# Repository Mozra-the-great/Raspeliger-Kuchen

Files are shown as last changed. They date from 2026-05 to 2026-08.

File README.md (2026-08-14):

# Raspeliger-Kuchen

Unser Raspberry Pi Challenge Projekt — ein dezentrales IoT-System zur intelligenten Raumverwaltung mit Buchungssystem, KI-basierter Personenerkennung und automatischer Komfortsteuerung.

---

## Projektbeschreibung

Das System verwaltet vier Meetingräume (A–D) und verbindet Buchungslogik, Umgebungssensorik und Raumsteuerung in einer einheitlichen Plattform. Kernfunktionen:

- **Raumbuchung** über ein Web-Dashboard (Touchscreen-Kiosk + Browser)
- **KI-Personenerkennung** per Kamera und Hailo-8L AI Accelerator (YOLOv8s)
- **Automatische Komfortsteuerung** Licht, Rollos und Klimaanlage schalten sich beim Betreten automatisch ein
- **No-Show Auto-Release** nicht angetretene Buchungen werden nach Timeout freigegeben
- **Live-Sensordaten** Temperatur, Luftfeuchte und CO₂ pro Raum mit Handlungsempfehlungen
- **Home Assistant Automationen** für die Komfortlogik

---

## Hardware

| Node | IP | Rolle | Hardware-Besonderheit |
|---|---|---|---|
| Pi 1 — Webserver | 192.168.1.211 | Flask-Webserver, REST-API, Hailo-8L KI (Personenerkennung) | Hailo-8L M.2 HAT+ (Firmware 4.23.0, identifiziert als "Hailo-8") |
| Pi 2 — Datenbank | 192.168.1.206 | MariaDB 11.8.6, Mosquitto MQTT-Broker, Raumfreigabe-Logik | — |
| Pi 3 — Sensorik | 192.168.1.233 | DHT22, SCD30 (CO₂), Kamera-Modul, UDP-Stream | I²C (`dtparam=i2c_arm=on`), CSI-Kamera (`camera_auto_detect=1`) |
| Pi 4 — Automatisierung | 192.168.1.210 | Home Assistant OS (Port 8123) | kein SSH (Web-UI + File-Editor-Add-on) |
| Pi 5 — GUI | 192.168.1.232 | Touchscreen-Kiosk (Chromium, labwc/Wayland) | Touchscreen (kapazitiv, HDMI-A-2) |

Netzwerk: alle Pis statisch über NetworkManager (`Wired connection 1`), Gateway 192.168.1.3, DNS 1.1.1.1 + 8.8.8.8.

---

## Tech-Stack

- **Backend:** Python / Flask 3.0.0, MariaDB 11.8.6, `paho-mqtt`, `pymysql`
- **Frontend:** Vanilla JS, HTML/CSS (Dark Theme, Kiosk-optimiert mit `clamp()`/`vw`/`vh`)
- **IoT:** MQTT (Mosquitto), Home Assistant OS
- **KI:** YOLOv8s (`yolov8s_h8l.hef`) auf Hailo-8L Accelerator (`hailort==4.23.0`)
- **Kamera:** `rpicam-vid` (1080p@30fps UDP) → `ffmpeg` (5 fps JPEG)
- **Sensoren:** DHT22 (Temp/Feuchte via `pigpio`), SCD30 (Temp/Feuchte/CO₂ via I²C/`adafruit-circuitpython-scd30`)
- **Wetter:** Open-Meteo API (Stuttgart)
- **OS:** Raspberry Pi OS Bookworm/Trixie 64-bit (Pi 1/2/3/5), Home Assistant OS (Pi 4), Pi 5 mit Wayland-Compositor `labwc`

---

## Repository-Struktur

```
.
├── app.py, person_detection.py, debug_server.py    Pi 1: Flask + KI
├── sensor_mqtt.py, DHT22.py, test_*.py             Pi 3: Sensor-Skripte
├── config.example.py                               Pi 1: Config-Template
├── *.service                                       systemd Units (Pi 1 + Pi 3)
├── configuration.yaml, automations.yaml,           Pi 4: Home Assistant
│   scripts.yaml, scenes.yaml, secrets.example.yaml
├── ha_automations_prod_v1.yaml,                    Pi 4: Komfort-Automationen
│   ha_automations_test_v2.yaml
├── schema.sql, raeume_seed.sql                     Pi 2: MariaDB
├── requirements_pi1.txt, requirements_pi3.txt      Pip-Pakete
├── install_emoji.sh                                Pi 5: Setup-Skript
├── README.md, ARCHITECTURE.md                      Doku
│
├── static/                                         Pi 1: Flask-Assets
│   ├── style.css, detail.css
│   └── dashboard.js, detail.js
├── templates/                                      Pi 1: Flask-Templates
│   ├── index.html
│   └── raum_detail.html
├── pi2/mosquitto/                                  Pi 2: MQTT-Config
│   ├── mosquitto.conf
│   └── conf.d/default.conf
├── pi3/                                            Pi 3: Boot-Config
│   └── boot_config.txt
└── pi5/                                            Pi 5: Kiosk-Setup
    ├── labwc-autostart
    ├── labwc-environment
    └── labwc-rc.xml
```

---

## Architektur

Eine vollständige Beschreibung aller Komponenten, Datenflüsse, MQTT-Topics und Setup-Schritte findet sich in [ARCHITECTURE.md](ARCHITECTURE.md).

---

## Lizenz

GNU General Public License v3.0 — siehe [LICENSE](LICENSE).

Das Projekt stand ursprünglich unter der MIT-Lizenz. Die Umstellung auf GPLv3
erfolgte 2026 mit Zustimmung aller Copyright-Inhaber (Moritz, Nick, Niklas, Robin).

`DHT22.py` enthält Code aus den pigpio-Beispielen (Joan2937, Public Domain).

---

*Robin, Nick, Niklas, Moritz — 2026*

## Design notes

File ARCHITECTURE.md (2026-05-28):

# Architektur: Raspeliger-Kuchen

Dezentrales IoT-System zur intelligenten Raumverwaltung mit Buchungen, KI-basierter Personenerkennung und automatischer Komfortsteuerung. Das System verteilt sich auf mehrere Raspberry Pi Nodes, die über MQTT kommunizieren, mit Home Assistant als zentraler Automationsschicht und Flask als Backend.

---

## Systemübersicht

```
┌──────────────────────────────────────────┐
│  Pi 3 — Sensorik (192.168.1.233)         │
│  kamera-stream.service:                  │
│    rpicam-vid 1080p@30fps                │
│    → UDP 192.168.1.211:9000              │
│  sensor.service:                         │
│    sensor_mqtt.py (DHT22 + SCD30)        │
│    → MQTT sensor/raum_a/*               │
└────────┬─────────────────────────────────┘
         │ UDP :9000          │ MQTT sensor/*
┌────────▼──────────────────────────────────────┐
│  Pi 1 — Webserver (192.168.1.211)              │
│                                                │
│  ffmpeg-stream.service:                        │
│    ffmpeg udp://@:9000 → /tmp/frame.jpg @5fps  │
│  person-detection.service:                     │
│    Hailo-8 YOLOv8s → MQTT room/raum_a/occupied │
│  debug-server.service → debug_server.py :5001  │
│  dashboard.service    → app.py :5000           │
└────────┬───────────────────────────────────────┘
         │ MQTT + MariaDB-Verbindung
┌────────▼──────────────────────────────────┐
│  Pi 2 — Datenbank (192.168.1.206)         │
│  MQTT Broker (Mosquitto) :1883            │
│  MariaDB :3306 (DB: raumverwaltung)       │
└────────┬──────────────────────────────────┘
         │ MQTT (cmd/*, room/*, state/*)
┌────────▼──────────────────────────────────┐
│  Pi 4 — Automatisierung (192.168.1.210)   │
│  Home Assistant :8123                     │
│  configuration.yaml, automations.yaml     │
│  ha_automations_prod_v1.yaml              │
└────────┬──────────────────────────────────┘
         │ HTTP
┌────────▼──────────────────────────┐
│  Pi 5 — GUI (192.168.1.232)       │
│  Touchscreen-Kiosk                │
│  Chromium → http://192.168.1.211  │
└───────────────────────────────────┘
```

---

## Netzwerk & IP-Adressen

| Node | IP | Rolle |
|---|---|---|
| Pi 1 — Webserver | 192.168.1.211 | Flask :5000, Hailo-8L KI, FFmpeg-Empfänger, Debug-Server :5001 |
| Pi 2 — Datenbank | 192.168.1.206 | MariaDB :3306, MQTT Broker :1883 |
| Pi 3 — Sensorik | 192.168.1.233 | DHT22, SCD30, Kamera-Streamer (UDP) |
| Pi 4 — Automatisierung | 192.168.1.210 | Home Assistant :8123 |
| Pi 5 — GUI | 192.168.1.232 | Touchscreen-Kiosk (Chromium, labwc) |

**Statische IPs via NetworkManager** (verifiziert 2026-05-28). Alle Pis nutzen Profil `Wired connection 1` auf `eth0`:
- `ipv4.method = manual`
- Gateway: `192.168.1.3`
- DNS: `1.1.1.1, 8.8.8.8` (Pi 5 hat nur `1.1.1.1`)

Beispiel-Konfiguration für einen neuen Pi:
```bash
sudo nmcli con modify "Wired connection 1" \
  ipv4.method manual \
  ipv4.addresses 192.168.1.XXX/24 \
  ipv4.gateway 192.168.1.3 \
  ipv4.dns "1.1.1.1,8.8.8.8"
sudo nmcli con up "Wired connection 1"
```

> Hinweis: Auf neueren Raspberry-Pi-OS-Versionen (Bookworm/Trixie) wird NetworkManager statt `dhcpcd` verwendet. `/etc/dhcpcd.conf` existiert dort nicht mehr.

---

## MQTT Topic-Schema

```
# Anwesenheit (Kamera-KI → app.py/HA)
room/raum_a/occupied          → "true" | "false"  (retain=true bei Release)

# Sensordaten (Sensor-Pi → app.py)
sensor/raum_a/temperatur      → float (°C)
sensor/raum_a/luftfeuchte     → float (%)
sensor/raum_a/co2             → int (ppm)
sensor/raum_a/dht22/temperatur → float (Rohwert DHT22)
sensor/raum_a/scd30/temperatur → float (Rohwert SCD30)

# Steuerbefehle (app.py → Hardware via HA)
cmd/raum_a/licht              ← "on" | "off"
cmd/raum_a/rollo              ← "up" | "down" | "stop"
cmd/raum_a/klima_modus        ← "off" | "heat" | "cool"
cmd/raum_a/klima_soll         ← "15"-"30" (int als String)

# Hardware-State-Feedback (Hardware → app.py)
state/raum_a/licht            → aktueller Zustand
state/raum_a/rollo            → aktueller Zustand
```

---

## Flask REST API (Pi 1 :5000)

Verifiziert aus `app.py`. Flask-Verzeichnis auf Pi 1: `/home/raspi/dashboard_mariadb/`

```
GET  /
     → render_template("index.html")

GET  /raum/<raum_id>
     → render_template("raum_detail.html", raum_id, raum_name)

GET  /api/raeume
     → [{name, belegt, nutzer, bis, naechste_buchung, anwesenheit}]
     # Sonderfall: MQTT occupied=true ohne Buchung → nutzer="Anwesend"

POST /buchen
     ← {raum, nutzer, start, ende}
     → {status: "ok"|"error", id|nachricht}

POST /buchen-schnell
     ← {raum, dauer_minuten, nutzer}
     → {status, id, start, ende}

GET  /api/raum/<raum_name>/buchungen?datum=YYYY-MM-DD
     → [{id, nutzer, start, ende, start_voll, ende_voll, status}]
     # status: "aktiv" | "geplant" | "vorbei"

GET  /api/raum/<raum_id>/anwesenheit
     → {occupied: bool|null, last_update: "YYYY-MM-DD HH:MM:SS"|null, alter_sek: int|null}

GET  /api/raum/<raum_name>/status
     → {licht, rollo, klima_modus, klima_soll, checkin, letzte_aenderung}

POST /api/raum/<raum_name>/licht
     ← {action: "on"|"off"|"toggle"}
     → {status: "ok", state: {...}}

POST /api/raum/<raum_name>/rollo
     ← {action: "up"|"stop"|"down"}
     → {status: "ok", state: {...}}

POST /api/raum/<raum_name>/klima
     ← {modus: "heat"|"cool"|"off"}  ODER  {soll: int (15-30)}
     → {status: "ok", state: {...}}

POST /api/raum/<raum_name>/checkin
     → {status: "ok", state: {...}}
     # Achtung: toggled nur In-Memory-Flag, schreibt NICHT checked_in_at in DB

GET  /api/sensoren
     → {temperatur, luftfeuchte, co2, zeitstempel, quelle, raum}
     # Liest HAUPT_RAUM aus config.py

GET  /api/sensoren/<raum_id>
     → {temperatur, luftfeuchte, co2, zeitstempel, raum}

GET  /api/raum/<raum_name>/verlauf
     → [{zeit, temperatur, luftfeuchte, co2}]  (24h, Demo-Daten)

GET  /api/wetter
     → {ort, current, forecast, tag, abgerufen}

GET  /api/verkehr
     → {status: "gruen"|"gelb"|"rot", label, beschreibung, details}

GET  /api/status
     → {zeit, db: "ok"|"error: ...", mqtt: {aktiv, raeume_mit_daten}}

POST /stornieren/<buchung_id>
     → {status: "ok"|"error", nachricht}

POST /raum/<raum_name>/frei
     → {status: "ok", id}  (HA No-Show-Trigger)
     # Setzt storniert=TRUE + publisht room/raum_x/occupied="false" (retain)
```

---

## Dateien

### `app.py` — Flask-Backend (Pi 1)

Zentrale Backend-Anwendung. Version 3. Liegt auf Pi 1 unter `/home/raspi/dashboard_mariadb/app.py`.

**Importiert aus `config.py`:**
```python
DB_CONFIG      # pymysql Verbindungsparameter
FLASK_HOST     # z.B. "0.0.0.0"
FLASK_PORT     # z.B. 5000
DEBUG          # bool
MQTT_CONFIG    # {host, port, username, password, keepalive}
MQTT_TOPICS    # Liste von Topics zum Subscriben
HAUPT_RAUM     # z.B. "raum_a" — Standard-Raum für /api/sensoren
MOCK_SENSORS   # bool — liefert Zufallswerte statt MQTT-Daten
MQTT_ENABLED   # bool
SCHWELLWERTE   # dict (wird importiert, aber in app.py nicht direkt verwendet)
```

**In-Memory-Caches (Thread-sicher via Locks):**

| Cache | Typ | Inhalt |
|---|---|---|
| `sensor_cache` | `{raum: {typ: (wert, datetime)}}` | Letzte MQTT-Sensorwerte |
| `belegung_cache` | `{raum: bool}` | Letzter `occupied`-Status |
| `belegung_timestamps` | `{raum: datetime}` | Zeitstempel des letzten MQTT-Updates |
| `control_state` | `{raum: {licht, rollo, klima_modus, klima_soll, checkin}}` | Gerätezustände (In-Memory, kein DB-Persist) |
| `wetter_cache` | `{data, ts}` | Wetter-Response, 10-Min TTL |
| `verkehr_cache` | `{status, last_change, next_change}` | Demo-Verkehrsstatus |

**MQTT `on_message` Routing:**
```
topic prefix "sensor/" → sensor_cache aktualisieren
topic prefix "room/"   → belegung_cache + belegung_timestamps aktualisieren
                         + mark_checked_in() aufrufen (Auto-Check-in)
topic prefix "state/"  → control_state aktualisieren
```

**`mark_checked_in(raum_anzeige)`:**
Wird bei MQTT `occupied=true` automatisch aufgerufen. Schreibt `checked_in_at = NOW()` in die DB auf die aktive Buchung — verhindert Auto-Release.

**`auto_release_loop()` — Background-Thread:**
- Läuft als Daemon-Thread, prüft alle 30 Sekunden
- SQL: `storniert=0 AND abgelaufen=0 AND checked_in_at IS NULL AND start <= NOW() - INTERVAL 1 MINUTE AND ende >= NOW()`
- Setzt `abgelaufen=1` (nicht `storniert`) — logisch unterschiedlich vom manuellen Storno
- **Achtung Bug:** Kommentar sagt "10 Min", SQL-Query löst aber bereits nach **1 Minute** aus

**Doppelter Auto-Release-Mechanismus:**
1. `auto_release_loop()` im Backend (alle 30s, SQL-basiert, setzt `abgelaufen=1`)
2. HA-Automation `ha_automations_prod_v1.yaml` (10-Min Timeout, setzt `storniert=TRUE` via `/raum/x/frei`)
Beide können unabhängig feuern — keine Deduplizierung.

**`fetch_verkehr()` — reines Demo:**
Simuliert Verkehr mit zufälligen Gewichtungen nach Tageszeit. Keine echte Verkehrs-API.

**Raum-ID Konvention:**
- URL-Parameter `raum_name` = `"raum_a"` (Kleinbuchstaben, Unterstrich)
- Intern: `raum_name.replace("_", " ").title()` → `"Raum A"` (für DB + control_state Key)
- `belegung_cache` Key: `raum["name"].lower().replace(" ", "_")` → `"raum_a"`

**Bekannter Bug — manueller Check-In:**
`POST /api/raum/<raum>/checkin` toggled nur `control_state["checkin"]` im RAM.
`checked_in_at` in der DB wird **nicht** gesetzt.
Folge: Manueller Check-In über den Button verhindert den Auto-Release **nicht**.
Auto-Release läuft trotzdem. Nur MQTT-Anwesenheitserkennung schreibt in die DB.

---

### `config.py` — Konfiguration (Pi 1, gitignored)

Liegt unter `/home/raspi/dashboard_mariadb/config.py`. Enthält alle Secrets und Einstellungen die `app.py` importiert. Ist via `.gitignore` ausgeschlossen — `config.example.py` dient als sanitisiertes Template.

Tatsächliche Struktur:
```python
DB_CONFIG = {
    "host": "localhost",
    "port": 3306,
    "user": "...",
    "password": "...",
    "database": "..."
}
FLASK_HOST = "0.0.0.0"
FLASK_PORT = 5000
DEBUG = False
MQTT_CONFIG = {
    "host": "192.168.1.206",
    "port": 1883,
    "username": "raspi",
    "password": "raspi",
    "keepalive": 60
}
MQTT_TOPICS = ["sensor/#", "room/#", "state/#"]
HAUPT_RAUM = "raum_a"
MOCK_SENSORS = False
MQTT_ENABLED = True
SCHWELLWERTE = { ... }
```

---

### `configuration.yaml` — Home Assistant Hauptkonfiguration

Definiert alle MQTT-basierten Entities und REST-Sensoren.

**MQTT Lights** (`light.licht_raum_a/b/c/d`)
- Command-Topic: `cmd/raum_x/licht`
- Payloads: `on` / `off`
- `optimistic: true` — HA schaltet UI sofort, unabhängig vom Hardware-Feedback
- QoS: 1

**MQTT Covers** (`cover.rollo_raum_a/b/c/d`)
- Topics: `cmd/raum_x/rollo`
- Payload open/close/stop: `up` / `down` / `stop`
- QoS: 1

**MQTT Climate** (`climate.klima_raum_a/b/c/d`)
- Modi: `off`, `heat`, `cool`
- Mode-Command-Topic: `cmd/raum_x/klima_modus`
- Temperatur-Soll-Topic: `cmd/raum_x/klima_soll`
- Temperatur-Ist-Topic: `sensor/raum_x/temperatur`
- Bereich: 15–30°C, Schrittweite 1°C

**MQTT Sensors** (nur Raum A vollständig aktiviert)
- `sensor.temperatur_raum_a` ← `sensor/raum_a/temperatur`
- `sensor.luftfeuchte_raum_a` ← `sensor/raum_a/luftfeuchte`
- `sensor.co2_raum_a` ← `sensor/raum_a/co2`

**MQTT Binary Sensors** (`binary_sensor.anwesenheit_raum_a/b/c/d`)
- Topic: `room/raum_x/occupied`, Payloads: `"true"` / `"false"`
- Device-Class: `occupancy`

**MQTT Switches** (`switch.raum_a/b/c/d_belegt`)
- Topic: `room/raum_x/occupied`, Retain: true

**REST-Sensoren** (`sensor.buchung_aktiv_a/b/c/d`)
- Endpoint: `GET http://192.168.1.211:5000/api/raeume`, Poll: 30s
- Jinja2-Logik: `on` wenn `belegt == true` UND `nutzer != "Anwesend"`
- `"Anwesend"` ist der Sonder-Nutzername den `app.py` setzt wenn MQTT occupied=true aber keine Buchung aktiv ist — damit triggern reine Kamera-Erkennungen keine HA-Buchungsautomation

**REST-Command** (`rest_command.raum_frei`)
- `POST http://192.168.1.211:5000/raum/{raum_id}/frei`

---

### `automations.yaml` — HA Basisautomation

Einfache No-Show Auto-Release (Basisversion, ohne Komfortsteuerung).

Trigger: `sensor.buchung_aktiv_a/b/c/d` → `"on"`
Ablauf: Wartet 10 Min auf Anwesenheit → bei Timeout: `rest_command.raum_frei` + Notification
Mode: `parallel`, max. 4

---

### `ha_automations_prod_v1.yaml` — Produktionsautomationen

Vollständige Komfort- + No-Show-Automationen für alle 4 Räume.

Pro Raum jeweils 3 Blöcke:

**"Buchung Komfort"** (Trigger: `buchung_aktiv_x` → `"on"`)
- Licht AN, Rollo AUF, Klima ein (Mai–Sept: Kühlen 22°C, sonst: Heizen 21°C)
- Wartet 10 Min auf Anwesenheit — bei Timeout: Alles aus
- Mode: `restart`

**"Person erkannt"** (Trigger: `anwesenheit_raum_x` → `"on"`)
- Identische Komfort-Aktionen
- Mode: `single`, `max_exceeded: silent`

**"Person weg"** (Trigger: `anwesenheit_raum_x` → `"off"`)
- Bedingung: keine aktive Buchung
- Delay 2 Min → erneute Prüfung → Alles aus
- Mode: `restart`

**"No-Show Auto-Release"** (zentral, alle 4 Räume)
- Raum-ID aus `trigger.entity_id` extrahiert
- 10 Min Timeout → `rest_command.raum_frei` + Notification
- Mode: `parallel`, max. 4

---

### `ha_automations_test_v2.yaml` — Testautomationen

Identisch zu Prod, aber mit drastisch kürzeren Timeouts.

| | Prod | Test |
|---|---|---|
| Buchung Komfort Timeout | 10 Min | 10 Sek |
| Person weg Delay | 2 Min | 30 Sek |
| No-Show Release | 10 Min | 30 Sek |

Zusätzlich: "Buchung Ende" (Trigger: `buchung_aktiv_x` → `"off"`, Alles aus wenn niemand da)

---

### `index.html` — Haupt-Dashboard

Flask-Template (`render_template("index.html")`). Kiosk-Ansicht auf Pi 5.

Linke Spalte: Wetter Stuttgart, 3-Tage-Forecast, Sonnenauf/-untergang + UV, Verkehr
Rechte Spalte: 4 Raumkarten (Frei/Belegt, Nutzer, bis, nächste Buchung), Buchungsmodal

Im Repo unter `templates/index.html`. Auf Pi 1 deployed nach `/home/raspi/dashboard_mariadb/templates/index.html`.

---

### `raum_detail.html` — Raum-Detailseite

Flask-Template, aufgerufen von `GET /raum/<raum_id>`.
`raum_id` und `raum_name` werden als `data-*`-Attribute auf `<body>` gesetzt.

Sektionen: Header + Status-Badge, Sensoren-Zeile (3 Mini-Cards), Komfort-Card (Datum/KW + Anwesenheit), Buchungs-Timeline (3 Tabs), Steuerung (Licht/Rollo/Klima), Schnell-Aktionen, Toast

Im Repo unter `templates/raum_detail.html`. Auf Pi 1 deployed nach `/home/raspi/dashboard_mariadb/templates/raum_detail.html`.

---

### `style.css` — Styling Haupt-Dashboard

Dark Theme (`#0f172a` / `#1e293b`). Adaptives Layout für Touchscreen 800×480 und Laptop-Browser, vollständig responsive via `clamp()`, `vw`, `vh` — keine Media-Queries für Bildschirmbreite.

Akzent: `#38bdf8` (cyan). Status-Farben: Frei/Belegt-Badges (`#16a34a`/`#ef4444`), Verkehr-Ampel (grün/gelb/rot).

Buttons mind. 50 px hoch, touch-freundlich. Modal mit `backdrop-filter: blur(4px)`.

Im Repo unter `static/style.css`. Auf Pi 1 deployed nach `/home/raspi/dashboard_mariadb/static/style.css`.

---

### `detail.css` — Styling Raum-Detail

Dark Theme (`#0f172a` / `#1e293b`). Responsive via `clamp()` und Media-Query <520px Höhe.

Farben: OK `#22c55e`, Warn `#fbbf24`, Kritisch `#ef4444`, Unbekannt `#64748b`, Akzent `#38bdf8`

Im Repo unter `static/detail.css`. Auf Pi 1 deployed nach `/home/raspi/dashboard_mariadb/static/detail.css`.

---

### `dashboard.js` — Frontend-Logik Dashboard

Version `dropdowns-v2-20260527`. Polling-Intervalle:

| Funktion | Intervall | Endpoint |
|---|---|---|
| `updateClock()` | 1s | — |
| `ladeRaeume()` | 30s | `GET /api/raeume` |
| `ladeVerkehr()` | 60s | `GET /api/verkehr` |
| `ladeWetter()` | 600s | `GET /api/wetter` |

Buchungsmodal: `fuelleDatumOptionen()` (15 Tage), `fuelleZeitOptionen()` (8:00–18:00, 30-Min), `naechsteHalbeStunde()` (Vorauswahl). Speichern via `POST /buchen`.

Im Repo unter `static/dashboard.js`. Auf Pi 1 deployed nach `/home/raspi/dashboard_mariadb/static/dashboard.js`.

---

### `detail.js` — Frontend-Logik Raum-Detail

Version `compact-3sections-v10-20260527`. Polling-Intervalle:

| Funktion | Intervall | Endpoint |
|---|---|---|
| `loadPresence()` | 5s | `GET /api/raum/{id}/anwesenheit` |
| `loadControlState()` | 5s | `GET /api/raum/{id}/status` |
| `loadSensors()` | 10s | `GET /api/sensoren/{id}` |
| `loadBookings()` | 30s | `GET /api/raum/{id}/buchungen?datum=...` |

Sensor-Schwellwerte:

| Sensor | OK | Warn | Kritisch |
|---|---|---|---|
| Temperatur | 19–24°C | 17–26°C | außerhalb |
| Luftfeuchte | 40–60% | 30–70% | außerhalb |
| CO2 | 0–1000 ppm | 0–1400 ppm | >1400 ppm |

Timeline: Zeitbereich 07:00–20:00, Lane-System für Überlappungen, Jetzt-Linie (nur heute).
Anwesenheit: `true` → 👤 blau, `false` → 🚪 grau, `null` → ⏳ grau.

Im Repo unter `static/detail.js`. Auf Pi 1 deployed nach `/home/raspi/dashboard_mariadb/static/detail.js`.

---

### `person_detection.py` — KI-Personenerkennung (Pi 1)

YOLOv8s auf Hailo-8 AI Accelerator. Liest `/tmp/frame.jpg` (von Pi 3), führt Inferenz durch, publisht `room/raum_a/occupied`.

Glättung: Sliding Window über 5 Frames — `true` nur wenn ≥3 von 5 positiv.
Fallback: `last_good_frame` wenn Frame nicht lesbar.

```python
MQTT_HOST = "192.168.1.206"
CONFIDENCE = 0.3
SEND_INTERVAL = 5
HEF_PATH = "/usr/share/hailo-models/yolov8s_h8l.hef"
```

---

### `sensor_mqtt.py` — Sensor-Publisher (Pi 3)

DHT22 (GPIO 4) + SCD30 (I2C). Publiziert sekündlich an `sensor/raum_a/*`.
Primary: SCD30, Fallback: DHT22. Je 10 Leseversuche mit Delay.

---

### `debug_server.py` — Kamera-Debug (Pi 1, :5001)

MJPEG-Stream mit eingezeichneten Bounding Boxes. Liest `/tmp/frame.jpg` + `/tmp/detections.json`.
Rotiert Frame 180° (Kamera hängt umgekehrt). Qualität 70, 500ms Delay.

---

### `stream_test.py` — Einmaliger Verbindungstest

Liest einen Frame von `udp://@:9000` und speichert nach `/home/raspi/test_stream.jpg`. Zur Verifikation des UDP-Streams von Pi 3.

---

### `patch_anwesenheit.py` — Einmaliger Patch (veraltet)

Fügte `belegung_timestamps` und `/api/raum/<id>/anwesenheit` zu einer älteren Version von `app.py` hinzu. Beide Features sind in der aktuellen `app.py` bereits integriert — dieses Skript ist obsolet.

---

### `patch_buchungen.py` — Einmaliger Patch (veraltet)

Ersetzte den alten Buchungs-Endpoint durch die datumsgefilterte Version mit Status-Berechnung. Ebenfalls in der aktuellen `app.py` integriert — obsolet.

---

### `raeume_seed.sql` — Initialdaten Räume (Pi 2)

INSERT-Statements für die `raeume`-Tabelle, weil `schema.sql` nur die Tabellendefinition enthält (mit `kapazitaet DEFAULT 4`). Reale Kapazitäten weichen ab:
- Raum A: 6 Plätze
- Raum B: 4 Plätze
- Raum C: 8 Plätze
- Raum D: 4 Plätze

Einspielen nach `schema.sql`:
```bash
sudo mysql raumverwaltung < raeume_seed.sql
```

---

### `pi2/mosquitto/mosquitto.conf` + `conf.d/default.conf` — MQTT-Broker (Pi 2)

Spiegelung von `/etc/mosquitto/` auf Pi 2. Hauptkonfig lädt `conf.d/`. Listener auf 1883, `allow_anonymous false`, Auth über `/etc/mosquitto/passwd` (eine Zeile: `raspi:<hash>`).

Persistence in `/var/lib/mosquitto/`, Logfile in `/var/log/mosquitto/mosquitto.log`.

---

### `pi3/boot_config.txt` — Pi 3 Boot-Konfiguration

Spiegelung von `/boot/firmware/config.txt` auf Pi 3. Aktiviert I²C (für SCD30), Kamera (CSI auto-detect), und Grafiktreiber.

---

### `pi5/labwc-autostart` + `labwc-environment` + `labwc-rc.xml` — Touchscreen-Kiosk (Pi 5)

Pi-5-Konfiguration für Wayland-Compositor `labwc`. Spiegelung von `~/.config/labwc/`:
- `labwc-autostart` — Bash-Skript, startet Chromium-Kiosk auf `http://192.168.1.211:5000` nach 10 s Wait
- `labwc-environment` — Setzt XKB-Layout `de` und `XCURSOR_SIZE=24`
- `labwc-rc.xml` — Touchscreen-Mapping (`WaveShare WS170120` → `HDMI-A-2`, `mouseEmulation=yes`), Theme `PiXonyx`

Siehe Sektion **"Pi 5 — Touchscreen-Kiosk"** oben für Hinweise zum Inhalt der Autostart-Datei.

---

### `requirements_pi1.txt` + `requirements_pi3.txt` — Python-Pakete

Liste der pip-Pakete pro Pi (Flask, paho-mqtt, pymysql, opencv, numpy, hailort für Pi 1 — pigpio, adafruit-circuitpython-scd30, paho-mqtt, adafruit-blinka für Pi 3). Installation:
```bash
pip3 install -r requirements_piX.txt --break-system-packages
```

---

### `secrets.example.yaml` — HA Secrets Template (Pi 4)

Vorlage für `secrets.yaml` (echte Datei via `.gitignore` ausgeschlossen). Wird in HA mit `!secret <name>` referenziert.

---

### `install_emoji.sh` — Einmaliges Setup (Pi 5)

Installiert `fonts-noto-color-emoji` + `fonts-symbola`, rebuildet Font-Cache, startet Chromium neu.

> Hinweise: Im Kopfkommentar steht "Zielsystem: Pi 2 (192.168.1.232)" — IP 192.168.1.232 gehört aber zu Pi 5 (Pi 2 ist 192.168.1.206). Das Skript ruft am Ende `sudo systemctl restart kiosk` auf, ein `kiosk.service` existiert auf Pi 5 jedoch nicht (Chromium-Start läuft via labwc-autostart). Der Font-Install-Teil funktioniert davon unabhängig.

---

## Wichtige Datenflüsse

### Buchung erstellen

```
Browser (dashboard.js)
  → POST /buchen {raum, nutzer, start, ende}
  → Flask: INSERT INTO buchungen (belegt=1)
  ← {status: "ok", id}
  → ladeRaeume() + loadBookings() neu laden
```

### Buchung aktiviert → Komfort ein

```
HA REST-Sensor (alle 30s) → GET /api/raeume
  ← prüft: belegt=true UND nutzer != "Anwesend"
  → sensor.buchung_aktiv_x = "on"
  → Automation "Buchung Komfort" feuert
  → MQTT cmd/raum_x/licht = "on", rollo = "up"
  → MQTT cmd/raum_x/klima_modus = "heat"|"cool", klima_soll = "21"|"22"
```

### Person erkannt → Auto-Check-in

```
Pi 3 (kamera-stream.service):
  rpicam-vid → UDP 192.168.1.211:9000

Pi 1 (ffmpeg-stream.service):
  ffmpeg udp://@:9000 → /tmp/frame.jpg (5fps, immer überschrieben)

Pi 1 (person-detection.service):
  person_detection.py liest /tmp/frame.jpg
  → Hailo-8 YOLOv8s Inferenz
  → /tmp/detections.json
  → MQTT room/raum_a/occupied = "true"

app.py on_message():
  → belegung_cache["raum_a"] = True
  → mark_checked_in("Raum A")
    → UPDATE buchungen SET checked_in_at=NOW() WHERE id=<aktive>

HA: binary_sensor.anwesenheit_raum_a = "on"
  → Automation "Person erkannt" → Komfort einschalten

Detail-Frontend (5s): GET /api/raum/raum_a/anwesenheit
  ← {occupied: true, alter_sek: 2}
  → renderPresence() → 👤 "PERSON ERKANNT"
```

### No-Show — zwei parallele Mechanismen

```
[Weg 1: Backend auto_release_loop, alle 30s]
  SQL: start <= NOW() - INTERVAL 1 MINUTE AND checked_in_at IS NULL
  → UPDATE buchungen SET abgelaufen=1

[Weg 2: HA Automation, 10 Min Timeout]
  sensor.buchung_aktiv_x = "on" → wartet 10 Min auf Anwesenheit
  → POST /raum/raum_x/frei
  → UPDATE buchungen SET storniert=TRUE
  → MQTT room/raum_x/occupied = "false" (retain)
  → HA Notification

Beide können unabhängig feuern. abgelaufen=1 vs. storniert=TRUE sind
verschiedene Zustände — beide werden in Queries mit AND abgelaufen=0
AND storniert=FALSE ausgefiltert.
```

### Sensordaten anzeigen

```
Pi 3 (sekündlich) → MQTT sensor/raum_a/temperatur|luftfeuchte|co2
  → app.py on_message() → sensor_cache["raum_a"]

Detail-Frontend (10s): GET /api/sensoren/raum_a
  ← {temperatur: 22.5, luftfeuchte: 45.2, co2: 800}
  → bewerteWert() + sensorMessage() → Farben + Empfehlungen
```

---

## MariaDB-Schema (Pi 2 — Datenbank, 192.168.1.206, DB: `raumverwaltung`)

Verifiziert aus `schema.sql`. Läuft auf Pi 206 (192.168.1.206), nicht Pi 4.

```sql
CREATE TABLE raeume (
    id           INT AUTO_INCREMENT PRIMARY KEY,
    name         VARCHAR(50) NOT NULL UNIQUE,  -- z.B. "Raum A"
    mqtt_key     VARCHAR(20) UNIQUE,           -- z.B. "raum_a"
    kapazitaet   INT DEFAULT 4,
    aktiv        TINYINT DEFAULT 1,
    erstellt_am  DATETIME DEFAULT current_timestamp()
);
-- AUTO_INCREMENT=5 → 4 Räume angelegt (A–D)

CREATE TABLE buchungen (
    id            INT AUTO_INCREMENT PRIMARY KEY,
    raum          VARCHAR(50) NOT NULL,        -- z.B. "Raum A" (entspricht raeume.name)
    nutzer        VARCHAR(100) NOT NULL,
    start         DATETIME NOT NULL,
    ende          DATETIME NOT NULL,
    belegt        TINYINT DEFAULT 1,
    storniert     TINYINT DEFAULT 0,
    checked_in_at DATETIME DEFAULT NULL,       -- gesetzt bei MQTT occupied=true
    abgelaufen    TINYINT DEFAULT 0,           -- gesetzt von auto_release_loop()
    erstellt_am   DATETIME DEFAULT current_timestamp(),
    KEY idx_raum (raum),
    KEY idx_start (start),
    KEY idx_zeitraum (start, ende)
);
-- AUTO_INCREMENT=51 → ~50 Buchungen bereits erfasst

CREATE TABLE sensordaten (
    id           INT AUTO_INCREMENT PRIMARY KEY,
    raum         VARCHAR(50) NOT NULL,
    temperatur   DECIMAL(4,1),
    luftfeuchte  DECIMAL(4,1),
    co2          INT,
    zeitstempel  DATETIME DEFAULT current_timestamp(),
    KEY idx_raum_zeit (raum, zeitstempel)
);
-- Historisches Feature: Sensor-Verlauf sollte hier persistiert werden.
-- Wurde angedacht aber nie fertig implementiert und wieder entfernt.
-- GET /api/raum/<raum>/verlauf gibt Mock-Daten zurück, Tabelle bleibt leer.
```

**Unterschied `storniert` vs. `abgelaufen`:**
- `storniert = 1`: manuelles Storno (User-Aktion oder HA-Automation via `/raum/x/frei`)
- `abgelaufen = 1`: automatisches Release durch `auto_release_loop()` im Backend (kein Check-in nach 1 Min)

---

## Nutzer & Räume

**Nutzer (hardcoded im Frontend):** Nick, Moritz, Niklas, Robin

**Räume:** Raum A, Raum B, Raum C, Raum D mit realen Kapazitäten 6/4/8/4 (siehe `raeume_seed.sql`).
- ID-Konvention: `"Raum A"` (DB/HA/control_state) ↔ `"raum_a"` (URL/MQTT/belegung_cache)
- Nur Raum A hat vollständige Sensor-Entities in `configuration.yaml`

> Hinweis: `schema.sql` setzt `kapazitaet INT DEFAULT 4` — die echten Werte (6/4/8/4) sind in `raeume_seed.sql` als INSERT versioniert.

**Sondernutzer `"Anwesend"`:** Wird von `app.py` gesetzt wenn MQTT `occupied=true` aber keine aktive Buchung. Der HA REST-Sensor schließt diesen Wert explizit aus damit reine Kamera-Erkennungen keine Komfort-Automation triggern.

---

## Pi 2 — MariaDB + Mosquitto

### MariaDB

- Version: 11.8.6 (Debian Trixie)
- Datenbank: `raumverwaltung`
- App-User: `raspi-db@%` (Wildcard-Host für Remote-Zugriff von Pi 1)
- System-User: `mariadb.sys@localhost`, `mysql@localhost`, `root@localhost`
- `bind-address = 0.0.0.0` (in `/etc/mysql/mariadb.conf.d/50-server.cnf`) damit Remote-Verbindungen funktionieren

Setup (auf Pi 2 ausführen):
```sql
CREATE DATABASE raumverwaltung CHARACTER SET utf8mb4 COLLATE utf8mb4_uca1400_ai_ci;
CREATE USER 'raspi-db'@'%' IDENTIFIED BY 'CHANGE_ME';
GRANT ALL ON raumverwaltung.* TO 'raspi-db'@'%';
FLUSH PRIVILEGES;
```
Anschließend `schema.sql` einspielen, dann `raeume_seed.sql`:
```bash
sudo mysql raumverwaltung < schema.sql
sudo mysql raumverwaltung < raeume_seed.sql
```

### Mosquitto

Konfiguration im Repo unter `pi2/mosquitto/` (Spiegelung von `/etc/mosquitto/` auf Pi 2):
- `mosquitto.conf` — Hauptdatei, lädt `conf.d/*.conf`, persistence in `/var/lib/mosquitto/`, Log in `/var/log/mosquitto/mosquitto.log`
- `conf.d/default.conf`:
  ```
  listener 1883
  allow_anonymous false
  password_file /etc/mosquitto/passwd
  ```

User in `/etc/mosquitto/passwd` (verifiziert via `sudo cut -d: -f1`):
- `raspi` (Passwort identisch — siehe `config.py`, `sensor_mqtt.py`, `person_detection.py`)

passwd-File anlegen (auf Pi 2):
```bash
sudo mosquitto_passwd -c /etc/mosquitto/passwd raspi
sudo systemctl restart mosquitto
```

---

## Pi 3 — Boot-Config

Datei `pi3/boot_config.txt` spiegelt `/boot/firmware/config.txt` auf Pi 3. Relevante Einträge:
- `dtparam=i2c_arm=on` — I²C für SCD30 (Sensor an Standard-I²C-Bus)
- `camera_auto_detect=1` — automatische Erkennung des CSI-Kamera-Moduls
- `dtoverlay=vc4-kms-v3d` — Grafiktreiber
- **Kein UART-Overlay** — der ursprünglich geplante MH-Z19B (UART) wurde durch den SCD30 (I²C) ersetzt.

`pigpiod`-Service muss aktiv sein (wird von `sensor.service` als Requirement geführt):
```bash
sudo apt install pigpio
sudo systemctl enable --now pigpiod
```

---

## Pi 1 — Hailo-8L Setup

Verifiziert via `hailortcli fw-control identify`:
- Board: "Hailo-8" (Family-Name; physisch ist es ein Hailo-8L)
- Firmware: 4.23.0
- Driver: 4.23.0 (`hailort==4.23.0`)
- HEF-Modelle vorinstalliert unter `/usr/share/hailo-models/`

Verwendetes Modell: `yolov8s_h8l.hef` (siehe `person_detection.py` Z. 13).
Weitere vorinstallierte Modelle die nicht verwendet werden: `yolov8s_pose_h8l_pi.hef`, `yolov5s_personface_h8l.hef`, `scrfd_2.5g_h8l.hef`, `resnet_v1_50_h8l.hef`, `yolov6n_h8l.hef`, u.a. (21 HEFs insgesamt).

Installation (auf Pi 1):
```bash
sudo apt install hailo-all          # zieht Treiber + hailort + Modelle
hailortcli fw-control identify      # Test
```
M.2-HAT+ aktivieren erfordert PCIe-Eintrag in `/boot/firmware/config.txt` (`dtparam=pciex1`).

---

## Pi 5 — Touchscreen-Kiosk (labwc/Wayland)

Pi 5 läuft auf Raspberry Pi OS Bookworm/Trixie mit **labwc** als Wayland-Compositor (Default seit Bookworm), nicht X11/LXDE. Konfiguration im Repo unter `pi5/`:

- **`labwc-autostart`** (entspricht `~/.config/labwc/autostart`):
  - 10 s Wait nach Boot
  - Startet Chromium im Kiosk-Modus auf `http://192.168.1.211:5000`
  - Startet zusätzlich eine zweite Chromium-Instanz mit `--start-maximized` (in derselben Zeile mit `&` verkettet — vermutlich Iterations-Rest, beide laufen parallel im Hintergrund)
  - Ruft anschließend `~/switchtab.sh` auf — dieses Skript existiert auf dem Pi nicht (Aufruf wirft seit dem 22.04. in `~/.xsession-errors` einen Fehler, beeinträchtigt den Kiosk-Betrieb aber nicht weil die Chromium-Aufrufe davor bereits im Hintergrund laufen).

- **`labwc-environment`** (entspricht `~/.config/labwc/environment`):
  - XKB-Layout `de` (deutsche Tastatur)
  - `XCURSOR_SIZE=24`

- **`labwc-rc.xml`** (entspricht `~/.config/labwc/rc.xml`):
  - Touchscreen-Mapping: `<touch deviceName="WaveShare WS170120" mapToOutput="HDMI-A-2" mouseEmulation="yes"/>`
  - Theme: PiXonyx, Schriftart Nunito Sans 12pt Light

Touchscreen-Modell: **WaveShare WS170120** (kapazitiv, 800×480, HDMI-A-2).

Optional: Emoji-Font-Setup über `install_emoji.sh` (Hinweis: das darin enthaltene `systemctl restart kiosk` bezieht sich auf einen nicht existierenden Service — die Datei `install_emoji.sh` benennt im Kopfkommentar "Pi 2" als Zielsystem, gehört aber auf Pi 5; das Skript funktioniert trotzdem für den Font-Install-Teil).

---

## systemd-Services

Insgesamt 5 systemd-Unit-Files im Repo:

| Service | Pi | Start | `User=` |
|---|---|---|---|
| `dashboard.service` | Pi 1 | `python3 /home/raspi/dashboard_mariadb/app.py` | `raspi` |
| `ffmpeg-stream.service` | Pi 1 | `ffmpeg ... -i udp://@:9000 -vf fps=5 -update 1 /tmp/frame.jpg` | `raspi` |
| `person-detection.service` | Pi 1 | `python3 /home/raspi/person_detection.py` | *(nicht gesetzt — läuft als root)* |
| `debug-server.service` | Pi 1 | `python3 /home/raspi/debug_server.py` | *(nicht gesetzt — läuft als root)* |
| `kamera-stream.service` | Pi 3 | `rpicam-vid ... -o udp://192.168.1.211:9000` | `raspi` |
| `sensor.service` | Pi 3 | `python3 /home/raspi/sensor_mqtt.py` | `raspi` |

> Hinweis: `person-detection.service` und `debug-server.service` definieren keinen `User=`-Eintrag, laufen daher als `root`. Die anderen Services laufen als `raspi`. Das ist gewollt für die Hailo-Inferenz (PCIe-Device-Zugriff), für `debug_server.py` aber technisch unnötig.

---

## Deployment

| Pi | Repo-Pfad | Ziel auf Pi | Services |
|---|---|---|---|
| Pi 1 — Webserver | Root (`app.py`, `config.py`, `person_detection.py`, `debug_server.py`, `stream_test.py`), `static/*`, `templates/*` | `/home/raspi/dashboard_mariadb/{app.py, config.py, ..., static/, templates/}` | `dashboard.service`, `ffmpeg-stream.service`, `person-detection.service`, `debug-server.service` |
| Pi 2 — Datenbank | `schema.sql`, `raeume_seed.sql`, `pi2/mosquitto/*` | DB-Setup + `/etc/mosquitto/{mosquitto.conf, conf.d/}` | MariaDB, Mosquitto (Distro-Pakete) |
| Pi 3 — Sensorik | Root (`sensor_mqtt.py`, `DHT22.py`, `test_dht.py`, `test_co2.py`), `pi3/boot_config.txt` | `/home/raspi/*.py`, `/boot/firmware/config.txt` | `kamera-stream.service`, `sensor.service`, `pigpiod.service` |
| Pi 4 — Automatisierung | `configuration.yaml`, `automations.yaml`, `ha_automations_prod_v1.yaml`, `ha_automations_test_v2.yaml`, `scripts.yaml`, `scenes.yaml`, `secrets.example.yaml` | `/config/` (Home Assistant) | Home Assistant OS |
| Pi 5 — GUI | `pi5/labwc-*`, `install_emoji.sh` | `~/.config/labwc/{autostart, environment, rc.xml}` | labwc-Autostart (kein systemd) |

**Für Produktion:** `ha_automations_prod_v1.yaml` in HA laden (10 Min Timeouts).
**Für Tests:** `ha_automations_test_v2.yaml` (10 s / 30 s Timeouts).

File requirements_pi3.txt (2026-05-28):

# Pi 3 (Sensorik) — Python Pakete
# Verifiziert am 2026-05-28 via pip3 freeze
#
# Verwendet von:
#   - sensor_mqtt.py    (pigpio, paho-mqtt, adafruit-circuitpython-scd30, board)
#   - DHT22.py          (pigpio — eigene Klasse, kein Adafruit-DHT)
#   - test_co2.py       (adafruit-circuitpython-scd30)
#   - test_dht.py       (pigpio)
#
# Installation auf Pi 3:
#   pip3 install -r requirements_pi3.txt --break-system-packages
#
# Zusaetzlich systemd-Service: pigpiod.service muss aktiv sein
#   sudo apt install pigpio
#   sudo systemctl enable --now pigpiod

paho-mqtt
pigpio
adafruit-circuitpython-scd30
adafruit-blinka

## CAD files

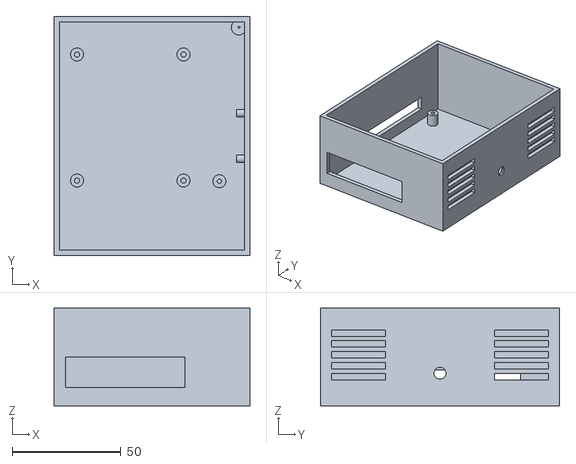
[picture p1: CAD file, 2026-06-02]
3D-Sensor-Pi-Gehäuse.stl
90.0 x 110.0 x 45.0

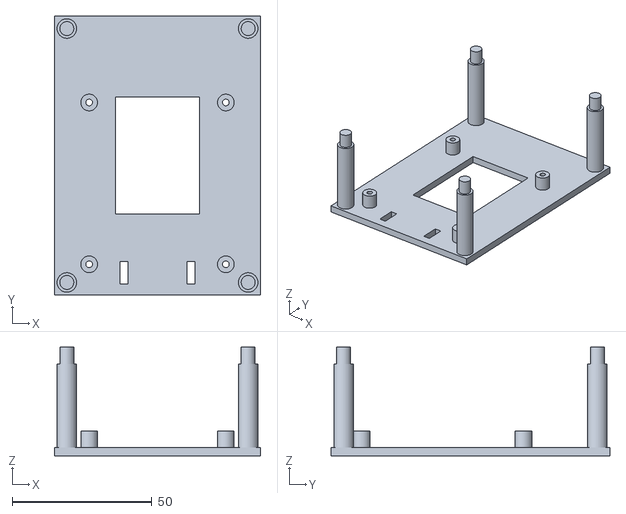
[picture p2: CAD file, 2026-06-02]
3D-Rack-3x-Pi.stl
74.0 x 100.0 x 39.0

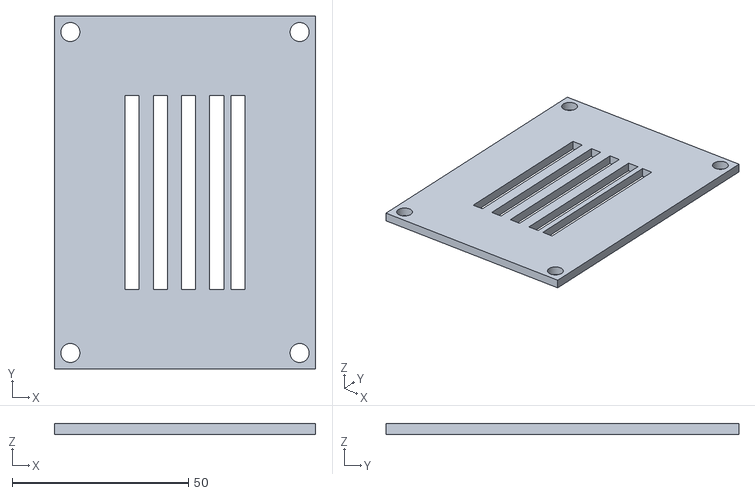
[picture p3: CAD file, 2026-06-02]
3D-Deckel-Sensor-Pi-Box.stl
74.0 x 100.0 x 3.00

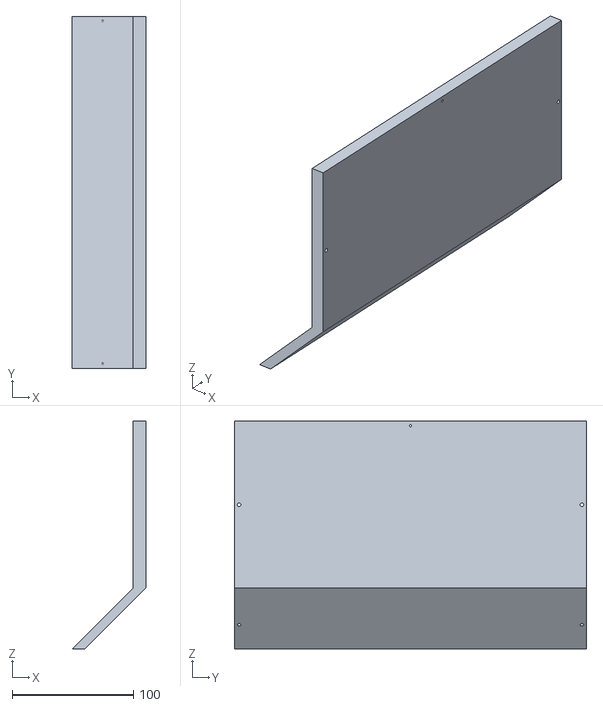
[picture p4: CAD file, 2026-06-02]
3D-Abdeckplatte-Bildschirm.stl
60.6 x 290.0 x 187.5

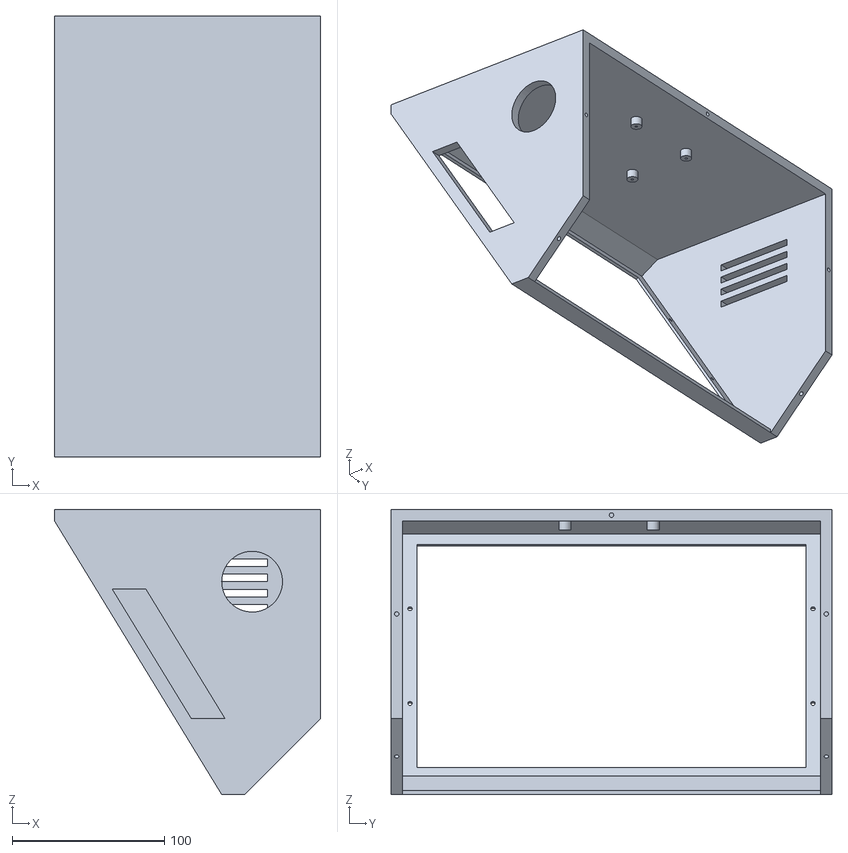
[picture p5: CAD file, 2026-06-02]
3D-Gehäuse-Bildschirm.stl
175.0 x 290.0 x 187.5

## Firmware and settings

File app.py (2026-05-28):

"""
Raumverwaltung Dashboard - v3
- Wetter (Open-Meteo, Stuttgart)
- Verkehr (Demo-Status)
- Buchungs-Anzeige nur wenn aktiv (Bugfix)
- Raum-Detail-View mit Steuerung
"""

from flask import Flask, render_template, jsonify, request
import pymysql
import pymysql.cursors
import random
import threading
import time
import urllib.request
import urllib.parse
import json
from datetime import datetime, timedelta
from config import (
    DB_CONFIG, FLASK_HOST, FLASK_PORT, DEBUG,
    MQTT_CONFIG, MQTT_TOPICS, HAUPT_RAUM,
    MOCK_SENSORS, MQTT_ENABLED, SCHWELLWERTE
)

try:
    import paho.mqtt.client as mqtt
    MQTT_AVAILABLE = True
except ImportError:
    MQTT_AVAILABLE = False
    print("⚠️  paho-mqtt nicht installiert - MQTT deaktiviert")

app = Flask(__name__)

# ============================================
# CACHES
# ============================================
sensor_cache = {}
cache_lock = threading.Lock()
belegung_cache = {}
belegung_timestamps = {}

control_state = {}
control_lock = threading.Lock()

wetter_cache = {"data": None, "ts": 0}
wetter_lock = threading.Lock()

verkehr_cache = {"status": "gruen", "last_change": 0, "next_change": 300}
verkehr_lock = threading.Lock()


def get_control_state(raum):
    with control_lock:
        if raum not in control_state:
            control_state[raum] = {
                "licht": "off",
                "rollo": "up",
                "klima_modus": "off",
                "klima_soll": 22,
                "checkin": False,
                "letzte_aenderung": datetime.now().isoformat()
            }
        return dict(control_state[raum])


def set_control_state(raum, key, value):
    with control_lock:
        if raum not in control_state:
            control_state[raum] = {
                "licht": "off", "rollo": "up", "klima_modus": "off",
                "klima_soll": 22, "checkin": False,
                "letzte_aenderung": datetime.now().isoformat()
            }
        control_state[raum][key] = value
        control_state[raum]["letzte_aenderung"] = datetime.now().isoformat()
        return dict(control_state[raum])


# ============================================
# MQTT
# ============================================
def on_connect(client, userdata, flags, rc, properties=None):
    if rc == 0:
        print(f"✅ MQTT verbunden mit {MQTT_CONFIG['host']}")
        for topic in MQTT_TOPICS:
            client.subscribe(topic)
    else:
        print(f"❌ MQTT-Verbindung fehlgeschlagen (Code {rc})")


def on_message(client, userdata, msg):
    try:
        topic = msg.topic
        payload = msg.payload.decode("utf-8").strip()
        teile = topic.split("/")

        if teile[0] == "sensor" and len(teile) == 3:
            raum, typ = teile[1], teile[2]
            with cache_lock:
                if raum not in sensor_cache:
                    sensor_cache[raum] = {}
                sensor_cache[raum][typ] = (payload, datetime.now())

        elif teile[0] == "room" and len(teile) == 3 and teile[2] == "occupied":
            raum = teile[1]
            occupied = payload.lower() in ("true", "1", "yes")
            with cache_lock:
                belegung_cache[raum] = occupied
                belegung_timestamps[raum] = datetime.now()
            # Phase C.3: Auto-Check-in bei erkannter Anwesenheit
            if occupied:
                raum_anzeige = raum.replace("_", " ").title()
                mark_checked_in(raum_anzeige)

        elif teile[0] == "state" and len(teile) == 3:
            raum, typ = teile[1], teile[2]
            raum_name = raum.replace("_", " ").title()
            set_control_state(raum_name, typ, payload)

    except Exception as e:
        print(f"⚠️  MQTT-Parse-Fehler: {e}")


def mqtt_start():
    if not MQTT_AVAILABLE or not MQTT_ENABLED:
        return None
    try:
        client = mqtt.Client(mqtt.CallbackAPIVersion.VERSION2)
    except AttributeError:
        client = mqtt.Client()
    client.on_connect = on_connect
    client.on_message = on_message
    if MQTT_CONFIG.get("username"):
        client.username_pw_set(MQTT_CONFIG["username"], MQTT_CONFIG["password"])
    try:
        client.connect(MQTT_CONFIG["host"], MQTT_CONFIG["port"], MQTT_CONFIG.get("keepalive", 60))
        client.loop_start()
        return client
    except Exception as e:
        print(f"❌ MQTT-Start fehlgeschlagen: {e}")
        return None


mqtt_client = None


def mqtt_publish_command(raum, geraet, befehl):
    if not mqtt_client:
        return False
    raum_id = raum.lower().replace(" ", "_")
    topic = f"cmd/{raum_id}/{geraet}"
    try:
        mqtt_client.publish(topic, str(befehl))
        return True
    except Exception:
        return False


# ============================================
# DB-HELPER
# ============================================
def get_db():
    return pymysql.connect(
        **DB_CONFIG,
        cursorclass=pymysql.cursors.DictCursor,
        connect_timeout=5
    )


def parse_db_datetime(val):
    if isinstance(val, datetime):
        return val
    if not val:
        return None
    s = str(val).strip().replace("T", " ")
    for fmt in ("%Y-%m-%d %H:%M:%S", "%Y-%m-%d %H:%M"):
        try:
            return datetime.strptime(s[:19] if len(s) >= 19 else s, fmt)
        except ValueError:
            continue
    return None



# ============================================
# BUCHUNGS-HELPERS (Phase C.2)
# ============================================
def find_aktive_buchung(cursor, raum_anzeige):
    """Findet die aktuell laufende Buchung fuer den Raum (oder None)."""
    cursor.execute("""
        SELECT id, nutzer, start, ende, checked_in_at
        FROM buchungen
        WHERE raum = %s
          AND storniert = 0
          AND abgelaufen = 0
        ORDER BY start ASC
    """, (raum_anzeige,))
    jetzt = datetime.now()
    for b in cursor.fetchall():
        start_dt = parse_db_datetime(b["start"])
        ende_dt  = parse_db_datetime(b["ende"])
        if start_dt and ende_dt and start_dt <= jetzt <= ende_dt:
            return b
    return None


def mark_checked_in(raum_anzeige):
    """Setzt checked_in_at=NOW auf die aktive Buchung (falls vorhanden + nicht schon eingecheckt)."""
    try:
        with get_db() as conn:
            with conn.cursor() as cursor:
                aktive = find_aktive_buchung(cursor, raum_anzeige)
                if aktive and not aktive.get("checked_in_at"):
                    cursor.execute(
                        "UPDATE buchungen SET checked_in_at = NOW() WHERE id = %s",
                        (aktive["id"],)
                    )
                    conn.commit()
                    print(f"OK Auto-Check-in: Buchung #{aktive['id']} ({raum_anzeige}, {aktive['nutzer']})")
                    return aktive["id"]
    except Exception as e:
        print(f"WARN mark_checked_in error: {e}")
    return None


def auto_release_loop():
    """Background-Thread: alle 30s Buchungen ohne Check-in nach 10 Min freigeben."""
    import time
    while True:
        try:
            with get_db() as conn:
                with conn.cursor() as cursor:
                    cursor.execute("""
                        SELECT id, raum, nutzer
                        FROM buchungen
                        WHERE storniert = 0
                          AND abgelaufen = 0
                          AND checked_in_at IS NULL
                          AND start <= NOW() - INTERVAL 1 MINUTE
                          AND ende >= NOW()
                    """)
                    rows = cursor.fetchall()
                    for r in rows:
                        cursor.execute(
                            "UPDATE buchungen SET abgelaufen = 1 WHERE id = %s",
                            (r["id"],)
                        )
                        print(f"AUTO-RELEASE: Buchung #{r['id']} ({r['raum']}, {r['nutzer']}) — kein Check-in nach 10min")
                    conn.commit()
        except Exception as e:
            print(f"WARN auto_release_loop error: {e}")
        time.sleep(30)


# ============================================
# WETTER (Open-Meteo)
# ============================================
STUTTGART_LAT = 48.78
STUTTGART_LON = 9.18

WMO_CODES = {
    0:  {"icon": "☀️", "text": "Sonnig"},
    1:  {"icon": "🌤️", "text": "Heiter"},
    2:  {"icon": "⛅",  "text": "Wolkig"},
    3:  {"icon": "☁️", "text": "Bedeckt"},
    45: {"icon": "🌫️", "text": "Nebel"},
    48: {"icon": "🌫️", "text": "Reifnebel"},
    51: {"icon": "🌦️", "text": "Leichter Nieselregen"},
    53: {"icon": "🌦️", "text": "Nieselregen"},
    55: {"icon": "🌧️", "text": "Starker Nieselregen"},
    61: {"icon": "🌧️", "text": "Leichter Regen"},
    63: {"icon": "🌧️", "text": "Regen"},
    65: {"icon": "🌧️", "text": "Starker Regen"},
    71: {"icon": "🌨️", "text": "Leichter Schnee"},
    73: {"icon": "🌨️", "text": "Schnee"},
    75: {"icon": "❄️",  "text": "Starker Schnee"},
    77: {"icon": "🌨️", "text": "Schneegriesel"},
    80: {"icon": "🌦️", "text": "Schauer"},
    81: {"icon": "🌧️", "text": "Starke Schauer"},
    82: {"icon": "⛈️", "text": "Gewitterschauer"},
    95: {"icon": "⛈️", "text": "Gewitter"},
    96: {"icon": "⛈️", "text": "Gewitter mit Hagel"},
    99: {"icon": "⛈️", "text": "Schweres Gewitter"},
}


def fetch_wetter():
    now = time.time()
    with wetter_lock:
        if wetter_cache["data"] and (now - wetter_cache["ts"] < 600):
            return wetter_cache["data"]

    params = {
        "latitude": STUTTGART_LAT,
        "longitude": STUTTGART_LON,
        "current": "temperature_2m,relative_humidity_2m,apparent_temperature,is_day,weather_code,wind_speed_10m",
        "daily": "weather_code,temperature_2m_max,temperature_2m_min,sunrise,sunset,uv_index_max,precipitation_probability_max",
        "timezone": "Europe/Berlin",
        "forecast_days": 4,
    }
    url = "https://api.open-meteo.com/v1/forecast?" + urllib.parse.urlencode(params)

    try:
        with urllib.request.urlopen(url, timeout=8) as resp:
            raw = json.load(resp)

        cur = raw.get("current", {})
        daily = raw.get("daily", {})
        wcode = int(cur.get("weather_code", 0))
        wmo = WMO_CODES.get(wcode, {"icon": "❓", "text": f"Code {wcode}"})

        forecast = []
        days = daily.get("time", [])
        wochentage = ["Mo", "Di", "Mi", "Do", "Fr", "Sa", "So"]
        for i, d in enumerate(days):
            dc = int(daily["weather_code"][i])
            forecast.append({
                "datum": d,
                "tag":  wochentage[datetime.fromisoformat(d).weekday()],
                "icon": WMO_CODES.get(dc, {}).get("icon", "?"),
                "text": WMO_CODES.get(dc, {}).get("text", ""),
                "max":  round(daily["temperature_2m_max"][i]),
                "min":  round(daily["temperature_2m_min"][i]),
                "regen_pct": daily.get("precipitation_probability_max", [0]*len(days))[i] or 0,
            })

        sunrise = daily["sunrise"][0] if daily.get("sunrise") else None
        sunset  = daily["sunset"][0] if daily.get("sunset") else None
        uv      = daily["uv_index_max"][0] if daily.get("uv_index_max") else 0

        data = {
            "ort": "Stuttgart",
            "current": {
                "temp":       round(cur.get("temperature_2m", 0), 1),
                "feels_like": round(cur.get("apparent_temperature", 0), 1),
                "humidity":   cur.get("relative_humidity_2m", 0),
                "wind":       round(cur.get("wind_speed_10m", 0), 1),
                "is_day":     bool(cur.get("is_day", 1)),
                "icon":       wmo["icon"],
                "text":       wmo["text"],
            },
            "tag": {
                "sunrise": sunrise[-5:] if sunrise else "--:--",
                "sunset":  sunset[-5:] if sunset else "--:--",
                "uv":      round(uv or 0, 1),
            },
            "forecast": forecast,
            "abgerufen": datetime.now().strftime("%H:%M"),
        }

        with wetter_lock:
            wetter_cache["data"] = data
            wetter_cache["ts"] = now
        return data

    except Exception as e:
        print(f"⚠️  Wetter-API Fehler: {e}")
        return wetter_cache.get("data") or {"error": str(e)}


# ============================================
# VERKEHR (Demo)
# ============================================
def fetch_verkehr():
    now = time.time()
    with verkehr_lock:
        if now - verkehr_cache["last_change"] > verkehr_cache["next_change"]:
            stunde = datetime.now().hour
            if 7 <= stunde <= 9 or 16 <= stunde <= 19:
                verkehr_cache["status"] = random.choices(
                    ["gruen", "gelb", "rot"], weights=[20, 50, 30]
                )[0]
            elif 22 <= stunde or stunde <= 5:
                verkehr_cache["status"] = "gruen"
            else:
                verkehr_cache["status"] = random.choices(
                    ["gruen", "gelb", "rot"], weights=[70, 25, 5]
                )[0]
            verkehr_cache["last_change"] = now
            verkehr_cache["next_change"] = random.randint(300, 600)
        status = verkehr_cache["status"]

    info = {
        "gruen": {
            "status": "gruen",
            "label": "Frei",
            "beschreibung": "Verkehr läuft flüssig",
            "details": ["A8 frei", "A81 frei", "Innenstadt normal"]
        },
        "gelb": {
            "status": "gelb",
            "label": "Mäßig",
            "beschreibung": "Erhöhtes Verkehrsaufkommen",
            "details": ["A8 zähflüssig", "B14 stockend", "Stadtmitte voll"]
        },
        "rot": {
            "status": "rot",
            "label": "Stau",
            "beschreibung": "Stau auf Hauptstrecken",
            "details": ["A8: 12 km Stau", "Verzögerung 25 Min", "Umfahrung empfohlen"]
        },
    }
    return info[status]


# ============================================
# ROUTES
# ============================================
@app.route("/")
def index():
    return render_template("index.html")


@app.route("/raum/<raum_id>")
def raum_detail(raum_id):
    raum_name = raum_id.replace("_", " ").title()
    return render_template("raum_detail.html", raum_id=raum_id, raum_name=raum_name)


@app.route("/api/wetter")
def api_wetter():
    return jsonify(fetch_wetter())


@app.route("/api/verkehr")
def api_verkehr():
    return jsonify(fetch_verkehr())


@app.route("/api/sensoren")
def api_sensoren():
    if MOCK_SENSORS:
        return jsonify({
            "temperatur": round(21.5 + random.uniform(-1.5, 2.0), 1),
            "luftfeuchte": round(45 + random.uniform(-5, 10), 1),
            "co2": round(600 + random.uniform(-50, 400)),
            "zeitstempel": datetime.now().strftime("%H:%M:%S"),
            "quelle": "mock"
        })
    with cache_lock:
        raum_data = sensor_cache.get(HAUPT_RAUM, {})
        temp = raum_data.get("temperatur", (None, None))[0]
        hum  = raum_data.get("luftfeuchte", (None, None))[0]
        co2  = raum_data.get("co2", (None, None))[0]
        zeiten = [v[1] for v in raum_data.values() if v[1]]
        letzte = max(zeiten).strftime("%H:%M:%S") if zeiten else "–"
    return jsonify({
        "temperatur": float(temp) if temp else None,
        "luftfeuchte": float(hum) if hum else None,
        "co2": int(float(co2)) if co2 else None,
        "zeitstempel": letzte,
        "quelle": "mqtt",
        "raum": HAUPT_RAUM
    })


@app.route("/api/sensoren/<raum_id>")
def api_sensoren_raum(raum_id):
    if MOCK_SENSORS:
        return jsonify({
            "temperatur": round(21.5 + random.uniform(-1.5, 2.0), 1),
            "luftfeuchte": round(45 + random.uniform(-5, 10), 1),
            "co2": round(600 + random.uniform(-50, 400)),
            "zeitstempel": datetime.now().strftime("%H:%M:%S"),
            "raum": raum_id
        })
    with cache_lock:
        raum_data = sensor_cache.get(raum_id, {})
        temp = raum_data.get("temperatur", (None, None))[0]
        hum  = raum_data.get("luftfeuchte", (None, None))[0]
        co2  = raum_data.get("co2", (None, None))[0]
        zeiten = [v[1] for v in raum_data.values() if v[1]]
        letzte = max(zeiten).strftime("%H:%M:%S") if zeiten else "–"
    return jsonify({
        "temperatur": float(temp) if temp else None,
        "luftfeuchte": float(hum) if hum else None,
        "co2": int(float(co2)) if co2 else None,
        "zeitstempel": letzte,
        "raum": raum_id
    })


@app.route("/api/raeume")
def api_raeume():
    """Räume-Liste mit echter 'aktiv'-Prüfung (Bugfix)."""
    try:
        jetzt = datetime.now()
        with get_db() as conn:
            with conn.cursor() as cursor:
                cursor.execute("SELECT * FROM raeume WHERE aktiv = TRUE ORDER BY name")
                raeume = cursor.fetchall()
                for raum in raeume:
                    cursor.execute("""
                        SELECT id, nutzer, start, ende
                        FROM buchungen
                        WHERE raum = %s
                          AND storniert = FALSE
                          AND abgelaufen = 0
                        ORDER BY start ASC
                    """, (raum["name"],))
                    alle_buchungen = cursor.fetchall()

                    aktuell = None
                    for b in alle_buchungen:
                        start_dt = parse_db_datetime(b["start"])
                        ende_dt  = parse_db_datetime(b["ende"])
                        if start_dt and ende_dt and start_dt <= jetzt <= ende_dt:
                            aktuell = b
                            break

                    raum_key = raum["name"].lower().replace(" ", "_")
                    mqtt_belegt = belegung_cache.get(raum_key)

                    if aktuell:
                        ende_dt = parse_db_datetime(aktuell["ende"])
                        raum["belegt"] = True
                        raum["nutzer"] = aktuell["nutzer"]
                        raum["bis"]    = ende_dt.strftime("%H:%M") if ende_dt else None
                    else:
                        raum["belegt"] = False
                        raum["nutzer"] = None
                        raum["bis"]    = None

                    naechste = None
                    for b in alle_buchungen:
                        start_dt = parse_db_datetime(b["start"])
                        if start_dt and start_dt > jetzt:
                            naechste = b
                            break
                    if naechste:
                        start_dt = parse_db_datetime(naechste["start"])
                        raum["naechste_buchung"] = {
                            "nutzer": naechste["nutzer"],
                            "start":  start_dt.strftime("%H:%M") if start_dt else None,
                        }
                    else:
                        raum["naechste_buchung"] = None

                    raum["anwesenheit"] = mqtt_belegt

                    # Anwesenheit ueberschreibt belegt (auch ohne Buchung)
                    if not aktuell and mqtt_belegt:
                        raum["belegt"] = True
                        raum["nutzer"] = "Anwesend"
                        raum["bis"] = None
        return jsonify(raeume)
    except Exception as e:
        return jsonify({"error": str(e)}), 500


@app.route("/api/raum/<raum_name>/buchungen")
def api_raum_buchungen(raum_name):
    """Buchungen fuer Raum: pro Tag, Parameter ?datum=YYYY-MM-DD (default: heute)."""
    raum_anzeige = raum_name.replace("_", " ").title()
    try:
        jetzt = datetime.now()
        datum_str = request.args.get("datum")
        if datum_str:
            try:
                ziel_datum = datetime.strptime(datum_str, "%Y-%m-%d").date()
            except ValueError:
                return jsonify({"error": "Ungueltiges Datum"}), 400
        else:
            ziel_datum = jetzt.date()
        tag_start = datetime.combine(ziel_datum, datetime.min.time())
        tag_ende = tag_start + timedelta(days=1)

        with get_db() as conn:
            with conn.cursor() as cursor:
                cursor.execute("""
                    SELECT id, nutzer, start, ende
                    FROM buchungen
                    WHERE raum = %s AND storniert = FALSE AND abgelaufen = 0
                """, (raum_anzeige,))
                rohdaten = cursor.fetchall()

        ergebnisse = []
        for b in rohdaten:
            start_dt = parse_db_datetime(b["start"])
            ende_dt  = parse_db_datetime(b["ende"])
            if not start_dt or not ende_dt:
                continue
            if ende_dt <= tag_start or start_dt >= tag_ende:
                continue
            if start_dt > ende_dt:
                start_dt, ende_dt = ende_dt, start_dt
            if ende_dt < jetzt:
                status = "vorbei"
            elif start_dt <= jetzt <= ende_dt:
                status = "aktiv"
            else:
                status = "geplant"
            ergebnisse.append({
                "id": b["id"],
                "nutzer": b["nutzer"],
                "start": start_dt.strftime("%H:%M"),
                "ende":  ende_dt.strftime("%H:%M"),
                "start_voll": start_dt.strftime("%Y-%m-%d %H:%M"),
                "ende_voll":  ende_dt.strftime("%Y-%m-%d %H:%M"),
                "status": status
            })
        ergebnisse.sort(key=lambda x: x["start"])
        return jsonify(ergebnisse)
    except Exception as e:
        return jsonify({"error": str(e)}), 500
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

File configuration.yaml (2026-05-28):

# ===================================================
# HA CONFIGURATION — Komplett, Stand 27.05.2026
# Topic-Flow:
#   Bedienpanel --> cmd/raum_x/...        --> HA + Geräte reagieren
#   Kamera (KI) --> room/raum_x/occupied  --> HA + Bedienpanel
#   HA          --> POST /raum/x/frei     --> Flask storniert Buchung
# ===================================================

default_config:

frontend:
  themes: !include_dir_merge_named themes

automation: !include automations.yaml
script: !include scripts.yaml
scene: !include scenes.yaml


# ===================================================
# MQTT
# Wichtig: optimistic = true  -->  HA schaltet sofort
# beim Empfang einer Command-Nachricht
# ===================================================
mqtt:

  # ---------- LICHTER ----------
  light:
    - name: "Licht Raum A"
      unique_id: "li_raum_a"
      command_topic: "cmd/raum_a/licht"
      state_topic:   "cmd/raum_a/licht"
      payload_on:  "on"
      payload_off: "off"
      optimistic: true
      qos: 1

    - name: "Licht Raum B"
      unique_id: "li_raum_b"
      command_topic: "cmd/raum_b/licht"
      state_topic:   "cmd/raum_b/licht"
      payload_on:  "on"
      payload_off: "off"
      optimistic: true
      qos: 1

    - name: "Licht Raum C"
      unique_id: "li_raum_c"
      command_topic: "cmd/raum_c/licht"
      state_topic:   "cmd/raum_c/licht"
      payload_on:  "on"
      payload_off: "off"
      optimistic: true
      qos: 1

    - name: "Licht Raum D"
      unique_id: "li_raum_d"
      command_topic: "cmd/raum_d/licht"
      state_topic:   "cmd/raum_d/licht"
      payload_on:  "on"
      payload_off: "off"
      optimistic: true
      qos: 1

  # ---------- ROLLOS ----------
  cover:
    - name: "Rollo Raum A"
      unique_id: "ro_raum_a"
      command_topic: "cmd/raum_a/rollo"
      state_topic:   "cmd/raum_a/rollo"
      payload_open:  "up"
      payload_close: "down"
      payload_stop:  "stop"
      state_open:    "up"
      state_closed:  "down"
      state_stopped: "stop"
      optimistic: true
      qos: 1

    - name: "Rollo Raum B"
      unique_id: "ro_raum_b"
      command_topic: "cmd/raum_b/rollo"
      state_topic:   "cmd/raum_b/rollo"
      payload_open:  "up"
      payload_close: "down"
      payload_stop:  "stop"
      state_open:    "up"
      state_closed:  "down"
      state_stopped: "stop"
      optimistic: true
      qos: 1

    - name: "Rollo Raum C"
      unique_id: "ro_raum_c"
      command_topic: "cmd/raum_c/rollo"
      state_topic:   "cmd/raum_c/rollo"
      payload_open:  "up"
      payload_close: "down"
      payload_stop:  "stop"
      state_open:    "up"
      state_closed:  "down"
      state_stopped: "stop"
      optimistic: true
      qos: 1

    - name: "Rollo Raum D"
      unique_id: "ro_raum_d"
      command_topic: "cmd/raum_d/rollo"
      state_topic:   "cmd/raum_d/rollo"
      payload_open:  "up"
      payload_close: "down"
      payload_stop:  "stop"
      state_open:    "up"
      state_closed:  "down"
      state_stopped: "stop"
      optimistic: true
      qos: 1

  # ---------- KLIMA ----------
  climate:
    - name: "Klima Raum A"
      unique_id: "kl_raum_a"
      modes: ["off", "heat", "cool"]
      mode_command_topic: "cmd/raum_a/klima_modus"
      mode_state_topic:   "cmd/raum_a/klima_modus"
      temperature_command_topic: "cmd/raum_a/klima_soll"
      temperature_state_topic:   "cmd/raum_a/klima_soll"
      current_temperature_topic: "sensor/raum_a/temperatur"
      min_temp: 15
      max_temp: 30
      temp_step: 1
      optimistic: true
      qos: 1

    - name: "Klima Raum B"
      unique_id: "kl_raum_b"
      modes: ["off", "heat", "cool"]
      mode_command_topic: "cmd/raum_b/klima_modus"
      mode_state_topic:   "cmd/raum_b/klima_modus"
      temperature_command_topic: "cmd/raum_b/klima_soll"
      temperature_state_topic:   "cmd/raum_b/klima_soll"
      current_temperature_topic: "sensor/raum_b/temperatur"
      min_temp: 15
      max_temp: 30
      temp_step: 1
      optimistic: true
      qos: 1

    - name: "Klima Raum C"
      unique_id: "kl_raum_c"
      modes: ["off", "heat", "cool"]
      mode_command_topic: "cmd/raum_c/klima_modus"
      mode_state_topic:   "cmd/raum_c/klima_modus"
      temperature_command_topic: "cmd/raum_c/klima_soll"
      temperature_state_topic:   "cmd/raum_c/klima_soll"
      current_temperature_topic: "sensor/raum_c/temperatur"
      min_temp: 15
      max_temp: 30
      temp_step: 1
      optimistic: true
      qos: 1

    - name: "Klima Raum D"
      unique_id: "kl_raum_d"
      modes: ["off", "heat", "cool"]
      mode_command_topic: "cmd/raum_d/klima_modus"
      mode_state_topic:   "cmd/raum_d/klima_modus"
      temperature_command_topic: "cmd/raum_d/klima_soll"
      temperature_state_topic:   "cmd/raum_d/klima_soll"
      current_temperature_topic: "sensor/raum_d/temperatur"
      min_temp: 15
      max_temp: 30
      temp_step: 1
      optimistic: true
      qos: 1
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

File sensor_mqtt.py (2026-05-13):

#!/usr/bin/env python3
"""
MQTT-Sender fuer Pi 33 (Sensor-Pi)
Nutzt die bestehende DHT22-Klasse und den SCD30 per I2C.
Sendet die Werte jede Sekunde an den MQTT-Broker auf Pi 206.
"""

import time
import sys
import signal
import paho.mqtt.client as mqtt

# ============================================
# KONFIGURATION
# ============================================
MQTT_HOST = "192.168.1.206"
MQTT_PORT = 1883
MQTT_USER = "raspi"
MQTT_PASS = "raspi"

RAUM_ID = "raum_a"
SEND_INTERVAL = 1           # Sekunden
DHT22_GPIO = 4
PRIMARY_TEMP_SENSOR = "scd30"  # "scd30" oder "dht22"

# ============================================
# SENSOREN INITIALISIEREN
# ============================================
print("Initialisiere Sensoren...")

dht_sensor = None
pi = None
try:
    import pigpio
    import DHT22
    pi = pigpio.pi()
    if not pi.connected:
        print("pigpio daemon nicht erreichbar - DHT22 deaktiviert")
        pi = None
    else:
        pi.set_pull_up_down(DHT22_GPIO, pigpio.PUD_UP)
        dht_sensor = DHT22.sensor(pi, DHT22_GPIO)
        time.sleep(1)
        print(f"DHT22 bereit (GPIO{DHT22_GPIO})")
except Exception as e:
    print(f"DHT22 Fehler: {e}")
    dht_sensor = None

scd_sensor = None
try:
    import board
    import adafruit_scd30
    i2c = board.I2C()
    scd_sensor = adafruit_scd30.SCD30(i2c)
    print("SCD30 bereit (I2C)")
    time.sleep(2)
except Exception as e:
    print(f"SCD30 Fehler: {e}")
    scd_sensor = None

if not dht_sensor and not scd_sensor:
    print("Kein Sensor verfuegbar. Abbruch.")
    sys.exit(1)

# ============================================
# SENSOR-LESEFUNKTIONEN
# ============================================
def read_dht22():
    if not dht_sensor:
        return None, None
    for versuch in range(10):
        try:
            dht_sensor.trigger()
            time.sleep(0.5)
            t = dht_sensor.temperature()
            h = dht_sensor.humidity()
            if t != -999 and h > 0:
                return round(t, 1), round(h, 1)
        except Exception:
            pass
        time.sleep(0.3)
    return None, None

def read_scd30():
    if not scd_sensor:
        return None, None, None
    for _ in range(10):
        if scd_sensor.data_available:
            try:
                t = round(scd_sensor.temperature, 1)
                h = round(scd_sensor.relative_humidity, 1)
                c = round(scd_sensor.CO2)
                return t, h, c
            except Exception as e:
                print(f"SCD30-Lesefehler: {e}")
                return None, None, None
        time.sleep(0.5)
    return None, None, None

# ============================================
# MQTT VERBINDEN
# ============================================
def on_connect(client, userdata, flags, rc, properties=None):
    if rc == 0:
        print(f"MQTT verbunden mit {MQTT_HOST}")
    else:
        print(f"MQTT-Verbindung fehlgeschlagen (Code {rc})")

try:
    client = mqtt.Client(mqtt.CallbackAPIVersion.VERSION2)
except AttributeError:
    client = mqtt.Client()

client.on_connect = on_connect
client.username_pw_set(MQTT_USER, MQTT_PASS)

print(f"Verbinde mit {MQTT_HOST}:{MQTT_PORT} ...")
try:
    client.connect(MQTT_HOST, MQTT_PORT, 60)
    client.loop_start()
except Exception as e:
    print(f"Konnte nicht zum Broker verbinden: {e}")
    sys.exit(1)

# ============================================
# GRACEFUL SHUTDOWN
# ============================================
def shutdown(signum, frame):
    print("\nStoppe...")
    try:
        if dht_sensor:
            dht_sensor.cancel()
        if pi and pi.connected:
            pi.stop()
    except Exception:
        pass
    client.loop_stop()
    client.disconnect()
    sys.exit(0)

signal.signal(signal.SIGINT, shutdown)
signal.signal(signal.SIGTERM, shutdown)

# ============================================
# HAUPT-LOOP
# ============================================
print(f"Sende alle {SEND_INTERVAL}s als Raum '{RAUM_ID}' (STRG+C zum Beenden)")

base = f"sensor/{RAUM_ID}"

while True:
    dht_t, dht_h = read_dht22()
    scd_t, scd_h, scd_c = read_scd30()

    if PRIMARY_TEMP_SENSOR == "scd30" and scd_t is not None:
        prim_t, prim_h = scd_t, scd_h
    elif PRIMARY_TEMP_SENSOR == "dht22" and dht_t is not None:
        prim_t, prim_h = dht_t, dht_h
    else:
        prim_t = scd_t if scd_t is not None else dht_t
        prim_h = scd_h if scd_h is not None else dht_h

    if prim_t is not None:
        client.publish(f"{base}/temperatur", str(prim_t))
    if prim_h is not None:
        client.publish(f"{base}/luftfeuchte", str(prim_h))
    if scd_c is not None:
        client.publish(f"{base}/co2", str(scd_c))
    if dht_t is not None:
        client.publish(f"{base}/dht22/temperatur", str(dht_t))
        client.publish(f"{base}/dht22/luftfeuchte", str(dht_h))
    if scd_t is not None:
        client.publish(f"{base}/scd30/temperatur", str(scd_t))
        client.publish(f"{base}/scd30/luftfeuchte", str(scd_h))

    t_str = f"{prim_t}C" if prim_t is not None else "-"
    h_str = f"{prim_h}%" if prim_h is not None else "-"
    c_str = f"{scd_c}ppm" if scd_c is not None else "-"
    print(f"{RAUM_ID}: {t_str} | {h_str} | {c_str}")

    time.sleep(SEND_INTERVAL)

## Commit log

2026-05-28 feat: Initial commit of Raumverwaltung Dashboard v3 with complete functionality
    - Added LICENSE file with MIT License.
    - Implemented main application logic in app.py, including:
    - Weather data fetching from Open-Meteo API.
    - Traffic simulation for demo purposes.
    - Room booking management with check-in functionality.
    - MQTT integration for real-time sensor data and control.
    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
2026-05-28 Add initial implementation of Raumverwaltung dashboard with CSS styling and HTML templates
    - Created style.css for dashboard layout and component styling
    - Added index.html for the main dashboard interface
    - Introduced raum_detail.html for room detail view with interactive elements
    [boot_config.txt]
2026-06-02 Refactor code structure for improved readability and maintainability
    [3D-Abdeckplatte-Bildschirm.stl, 3D-Deckel-Sensor-Pi-Box.stl, 3D-Gehäuse-Bildschirm.stl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]
